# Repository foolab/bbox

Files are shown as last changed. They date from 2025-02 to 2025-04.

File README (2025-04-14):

I have been using a Node 804 for my TrueNAS server for years but I needed a new case. The 804 is great but I needed something smaller that could be shoved in an IKEA Besta cabinet.
In addition to the drive trays making me nervous as I do not want to carry 4 drives just to replace one.

I actually bought a 3D printer and started learning CAD just for that. It's my first serious design.

Requirements:
 * Shallow as I neither have a rack nor the space for one.
 * Can be printed via my Qidi Q1 Pro
 * Can fit 6-8 drives
 * Can fit my HBA and an optional GPU
 * Can fit my mATX motherboard and ATX PSU
 * Easy access for hard drives
 * Drives are positioned so that the first 8 drives will clear out the PCIE zone.
 * No glue and no threaded inserts.

Dimensions: 430mm width, 375mm depth, 176.5mm height

BOM:
3 rolls of filament. Mine is around 1.8KG without any of the front drive holders.
86 x M2 10mm counterbore screws
86 x M2 hex nuts
51 x M3 10mm countersink screws
51 x M3 hex nuts
28 6x3 circular magnets
12mm M3 motherboard standoffs + M3 nuts.
16mm PC power switch

For each fan mount:
4 x M3 screws and 4 M3 nuts (to attach each mount to 4 hdd holders).
The shorter the better. 6mm would do. Maybe even 5mm but I had only 8mm and 10mm so used 8mm

For each HDD holder:
2 x M2.5 18mm counterbore screws and 2 x 2.5M nuts for attaching the connector
1 x SFF-8482 SAS Female to SATA Male 90 degrees connector https://www.aliexpress.com/item/1005008077051668.html?spm=a2g0o.order_list.order_list_main.75.d85f18023sqB9C

For each SSD holder:
up to 3 x SFF-8482 SAS to SATA 3.0 Adapter (SATA Male to Female) `https://www.aliexpress.com/item/1005005773620960.html?spm=a2g0o.order_list.order_list_main.124.d85f18023sqB9C
I could not connect the power to all 3 adapters so used 2. It was too tight.
2 x M2.5 30mm counterbore screws and 2 x 2.5M nuts for the connectors.
3 x M2.5 18mm counterbore screws and 3 x 2.5M nuts, 1 x M2 10mm counterbore screws and 1 x M2 nut for connecting all the body pieces (Shorter screws will do).

For each side SSD holder:
2 x M2.5 18mm counterbore screws and 2 x 2.5M nuts for attaching the connector AND THE STRUCTURE TO LEFT WALL.
1 x SFF-8482 SAS to SATA 3.0 Adapter (SATA Male to Female) `https://www.aliexpress.com/item/1005005773620960.html?spm=a2g0o.order_list.order_list_main.124.d85f18023sqB9C

M2.5 counterbore screws and nuts for attaching studs, HDD and SSD holders to the case (Amount depends on the number of drives used. read below).

Printing:
I used a Qidi Q1 Pro for printing. My nozzle is 0.4 and the layer height is 0.2.
I am using Orca slicer
I had to use a glue stick otherwise prints won't release (mesh would break instead of release).
I did not want to print with support thus some parts got split insanely (The intact versions are there).
Please make sure your printer is as accurate as possible. There is not much wiggle room.
I used a mix of black and white Elegoo rapid PETG and Sunlu white PETG.
The case seems to be a bit wider at the front. Probably due to warping but the front top should bring it together nicely.

Assembly:
Instructions assume the case is oriented so that front wall is towards us.

- Bottom:
 - I planned pockets for screw heads but it was easier to use them for the nuts.
 - Bolt middle left and middle right with 3 x M2 screws and 3 x M2 nuts
 - Bolt rear left and rear right with 5 x M2 screws and 5 x M2 nuts
 - Bolt rear and middle with 12 x M2 screws and 12 x M2 nuts
 - Install the 6 magnets in the corresponding pockets in middle part

- Rear wall
 - Bolt rear PSU to the bottom using 3 x M2 screws and 3 x M2 nuts
 - Bolt rear middle to the bottom using 3 x M2 screws and 3 x M2 nuts. There are 5 holes but only 3 are usable. I might fix that in a future iteration depending on how stable the structure is.
 - Bolt rear PCI to the bottom using 4 x M2 screws and 4 x M2 nuts

- Right wall
 - Bolt rear part to the bottom using 4 x M2 screws and 4 x M2 nuts
 - Bolt front part to the bottom using 4 x M2 screws and 4 x M2 nuts

- Left wall
 - Bolt rear part to the bottom using 4 x M2 screws and 4 x M2 nuts
 - Bolt front part to the bottom using 4 x M2 screws and 4 x M2 nuts
 - Bolt front left support to the left wall using 3 x M2 screws and 3 x M2 nuts

- Front wall
 - The power button holder:
  - attached to the left wall using 3 x M2 screws and 3 x M2 nuts.
  - attached to the bottom using 1 x M2 screws and 1 x M2 nuts.
 - mesh parts and bottom front bolted together
 - Attach bottom front
  - Install 6 magnets into the pockets.
  - Bolt it using 6 x M2 screws and 6 x M2 nuts
  - Orient it so that magnets are towards the front wall and the thick part is towards the bottom.
 - 2 front supports. Each takes a magnet and 6 x M2 screws and 6 x M2 nuts.

- Bolt left wall to PCIE cutouts part using 3 x M3 screws and nuts
- Bolt PCIE cutouts part to middle part using 4 x M3 screws and nuts
- Bolt middle part to PSU part using 4 x M3 screws and nuts
- Bolt PCIE top part to middle part using 4 x M3 screws and nuts
- Corner support between rear wall and right/left walls:
 - The thin part with the hole is oriented upwards.
 - Use 6x3mm circular magnet for each
 - Use 2 x M3 screws and 2 x M3 nuts for each

- Side supports:
 - 2 side supports
 - Each takes 2 magnets
 - Each needs 8 x M3 screws and 8 x M3 nuts

- Top
 - Front parts to be connected using front top support.
  - Each top support needs 6 x M2 screws and 6 x M2 nuts.
  - Each top support needs a magnet. Make sure the orientation is correct w.r.t front support magnets.
  - 2 Magnets for front rear. Use 2 x M3 screws and 2 x M3 nuts for each.
 - Rear parts to be screwed using 4 x M3 screws and 4 x M3 nuts.
  - 4 Magnets for the rear part. Use 2 x M3 screws and 2 x M3 nuts for each.

- Motherboard standoffs
 - The case supports both ATX and mATX motherboards. You can still use mini ITX if you want.
 - ATX-only locations are labeled "A"
 - mATX-only locations are labeled "M"
 - NOTE: Not all motherboards will have holes for all standoffs. Please check before screwing your notherboard
 - Standoffs:
  - My standoffs have 6mm bottom threads and are 6mm in height.
  - I screwed 2 standoffs on top of each others to get the 12mm needed.

- PCIE covers
 - Print as much as you need.
 - They just snap into place from the outside.

- SSD side holder:
 - Attach to the left wall using 2 x M2.5 screws and 2 x 2.5M nuts.
 - The thick holder wall is towards the side wall.
 - Make sure the connector is oriented correctly otherwise the SSD will not fit.

- SSD holder:
 - It will easily come together using the M2.5 screws.
 - Join the body pieces together with the M2 and M2.5 screws and nuts.

- HDD holder:
 - Attach the connector using 2 x M2.5 screws and 2 x 2.5M nuts.

- HDD fan mount:
 - Each fan mount attaches to 4 hdd holders using 4 x M3 screws and 4 M3 nuts
 - It is supposed to be flimsy to give space for removing the drives.
 - I recommend attaching the mounts to the holders after they are installed and afterwards attach the fan.

- Drive studs and holders:
 - I used a 1mm thick rubber strip hoping it will help with HDD vibrations. No idea if it does.
 - Make sure to attach all SATA data and power cables before screwing in the holders.
 - The space is very tight.
 - The case can host up to 12 holders but I recommend no more than 8 due to space being very tight.
 - The large stud is at the front. The small stud is towards the back.
 - Make sure the large stud is oriented correctly: There are tiny pockets that go above the magnets pockets
 - Screw in studs first. For each position:
  - If it will be empty, use 3 x M2.5 14mm screws
  - If it will host an SSD holder, use 1 x M2.5 14mm screw for the top hole in the large stud.
  - If it will host an HDD holder, use 1 x M2.5 14mm screw for the small stud.
 - Holders screw on top of the studs.
 - For the holders:
  - HDD: Use 2 x M2.5 25mm screws and 2 nuts.
  - SSD: Use 1 x M2.5 18mm screw for the amall stud and 1 x M2.5 25mm screw for the large stud and 2 nuts.
 - The screws might protrude from the bottom due to inaccuracies while printing. It can be solved by using washers between the studs and the drive holders. Do NOT put the washer inside the holder itself.

- Bottom plates:
 - Attach using 3 x M2 screws and 3 x M2 nuts (Even 2 will do).
 - There are holes for 4 screws but the rightmost one is inaccessible and the rest are too difficult.
 - I ended up not attaching them :p

- Fans:
 - Use the 30mm screws.
 - I used M2.5 with a washer to prevent the screw head from going through the hole :D
 - I recommend screwing in the fans after the motherboard installation.
 - I use Noctua NF-A12x25 fans. Maybe a 15 mm would be easier to install
 - The rear has screw holes for a 92mm fan.

- Attach the power button to its holder.
- PSU: I used 4 x 6-32 8mm screws.

Github: FreeCAD files available from https://github.com/foolab/bbox

Buy me a coffee: https://ko-fi.com/msameer

BBox? It can be Bit(s) Box, Bytes Box, Bolts Box or simply Broken Box ;-)

bottom (I think I mixed up front right and left):
  rear left: 5 top layers, 5 bottom layers, 4 walls, 15% grid infill, no brim, layer height: 0.2
  rear right: 5 top layers, 5 bottom layers, 4 walls, 15% grid infill, no brim, layer height: 0.2
  middle left: 5 top layers, 5 bottom layers, 4 walls, 15% grid infill, no brim, layer height: 0.2
  middle right: 5 top layers, 5 bottom layers, 4 walls, 15% grid infill, no brim, layer height: 0.2
  front: 5 top layers, 5 bottom layers, 4 walls, 15% grid infill, no brim, layer height: 0.2
  plates: 4 top layers, 4 bottom layers, 2 walls, 15% grid infill, no brim, layer height: 0.2

front wall:
 settings: 5 top layers, 5 bottom layers, 4 walls, 15% gyroid infill, no brim, layer height: 0.2
 mesh parts:
   Add part: cube
   cube part: 0 top layers and 0 bottom layers
    left:
      cube part position: x: -1.23, y: 5.5, z: 0
      cube part size: x: 120, y: 158.5, z: 3
    middle:
      cube part position: x: 0.4, y: 5.5, z: 0
      cube part size: x: 120, y: 158.5, z: 3
    right:
      cube part position: x: 0.82, y: 5.5, z: 0
      cube part size: x: 120, y: 158.5, z: 3

left wall:
  front: 5 top layers, 5 bottom layers, 4 walls, 15% grid infill, no brim, layer height: 0.2
  rear:
    settings: 5 top layers, 5 bottom layers, 4 walls, 15% gyroid infill, no brim, layer height: 0.2
    Add part: disc
    disc part: 0 top walls and 0 bottom walls
    disc part position: x: -8.54, y: 9.75, z: 0
    disc part size: x: 118, y: 118, z: 4

right wall:
  front: 5 top layers, 5 bottom layers, 4 walls, 15% grid infill, no brim, layer height: 0.2
  rear:
    settings: 5 top layers, 5 bottom layers, 4 walls, 15% gyroid infill, no brim, layer height: 0.2
    Add part: cube
    cube part: 0 top walls and 0 bottom walls
    cube part position: x: 8.54, y: -3.25, z: 0
    cube part size: x: 130, y: 146, z: 4

drive cage studs: 4 wall loops, 5 top layers, 5 bottom layers, 40% grid infill, no brim

rear:
  middle: 5 top layers, 5 bottom layers, 4 walls, 15% grid infill, no brim, layer height: 0.2
  psu: 5 top layers, 5 bottom layers, 4 walls, 15% grid infill, no brim, layer height: 0.2
  pcie combined: 5 top layers, 5 bottom layers, 4 walls, 15% grid infill, no brim, layer height: 0.2

top:
	rear left: 4 top layers, 4 bottom layers, 2 walls, 15% grid infill, no brim, layer height: 0.2
	rear right: 4 top layers, 4 bottom layers, 2 walls, 15% grid infill, no brim, layer height: 0.2
	front left: 4 top layers, 4 bottom layers, 2 walls, 15% grid infill, no brim, layer height: 0.2
	front middle: 4 top layers, 4 bottom layers, 2 walls, 15% grid infill, no brim, layer height: 0.2
	front right: 4 top layers, 4 bottom layers, 2 walls, 15% grid infill, no brim, layer height: 0.2

pcie slot cover: 2 top layers, 2 bottom layers, 2 walls, 10% grid infill, no brim, layer height: 0.2

supports and magnets: 5 top layers, 5 bottom layers, 4 walls, 15% grid infill, no brim, layer height: 0.2
ssd side holder: 5 top layers, 5 bottom layers, 4 walls, 15% grid infill, no brim, layer height: 0.2
ssd holder: 5 top layers, 5 bottom layers, 4 walls, 15% grid infill, no brim, layer height: 0.2
hdd fan mount: 4 top layers, 2 bottom layers, 4 walls, 40% grid infill, no brim, layer height: 0.2
hdd holder: 5 top layers, 5 bottom layers, 4 walls, 15% grid infill, no brim, layer height: 0.2

TODO:
rear middle has 5 screw holes but bottom has 4 pockets only.
rear middle 1 screw has no place for the bolt. too tight.
bottom plates, 1 screw is inaccessible and screws are too difficult
decrease motherboard standoff heights
bottom is too difficult to assemble
Increase the hdd holder base height by 1 mm
design a double side ssd holder

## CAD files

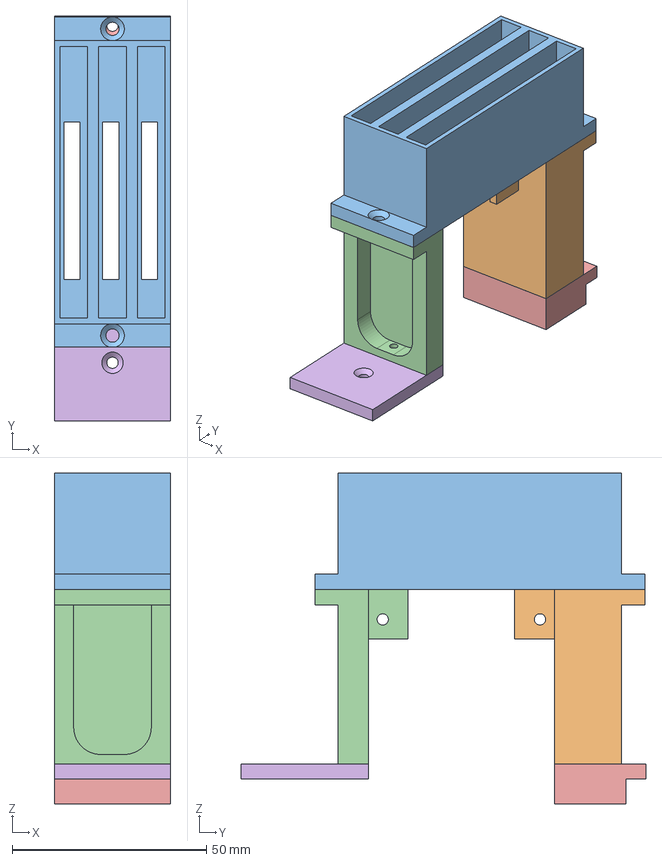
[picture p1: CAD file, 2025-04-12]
ssd holder.FCStd
30.0 x 104.3 x 85.2 mm
Slice.0
Slice.1
Slice.2
Slice.3
Slice.4

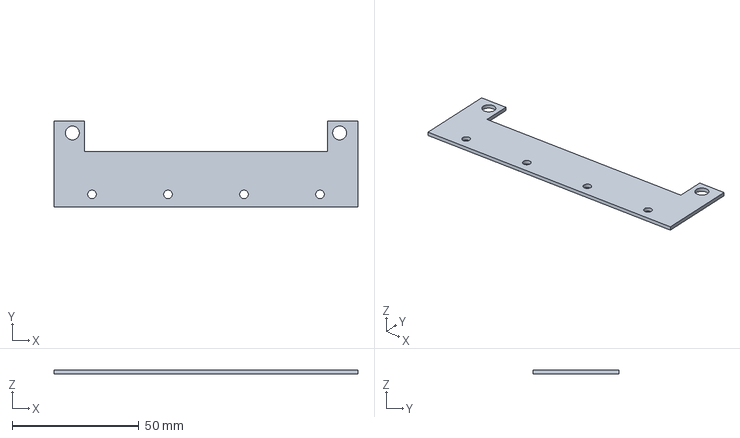
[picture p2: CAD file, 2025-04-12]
hdd fan mount.FCStd
120.0 x 34.0 x 1.50 mm

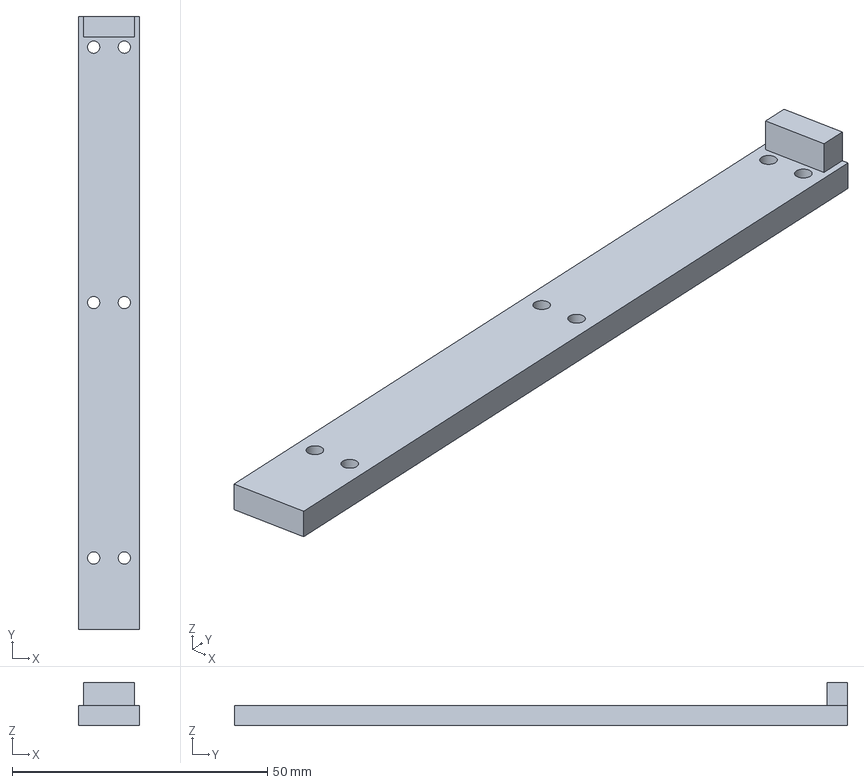
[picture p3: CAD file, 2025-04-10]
front support.FCStd
12.0 x 120.0 x 8.50 mm

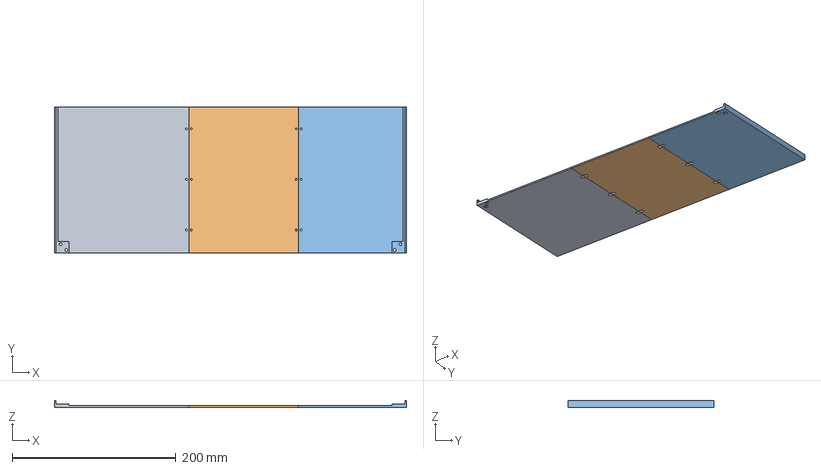
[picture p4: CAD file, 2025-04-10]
top.FCStd
430.0 x 178.0 x 8.00 mm
Slice001.0
Slice001.1
Slice001.2

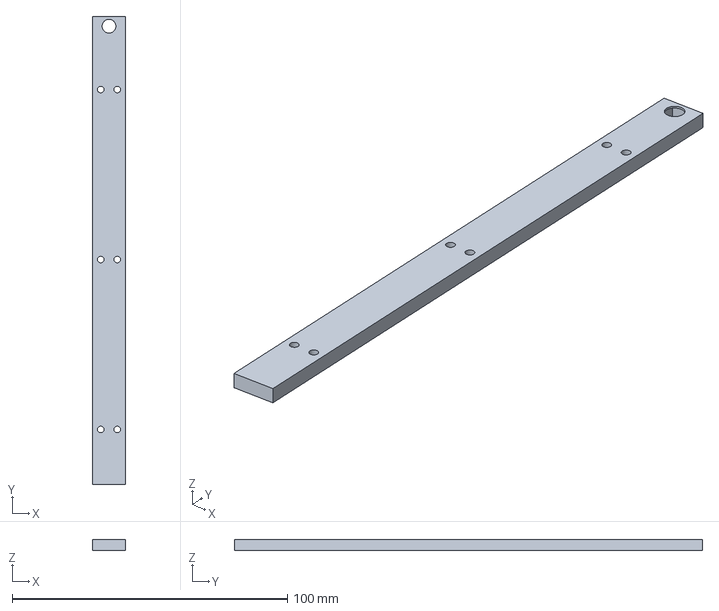
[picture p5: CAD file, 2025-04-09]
top front support.FCStd
12.0 x 170.0 x 4.00 mm

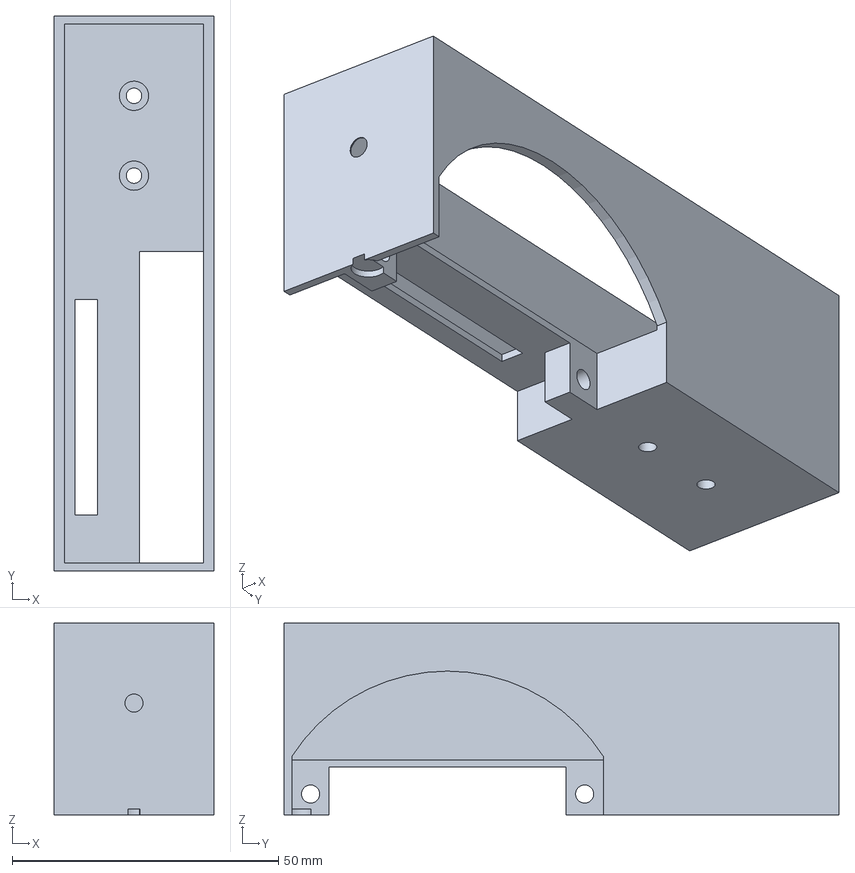
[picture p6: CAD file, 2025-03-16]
hdd holder.FCStd
30.0 x 104.3 x 36.0 mm

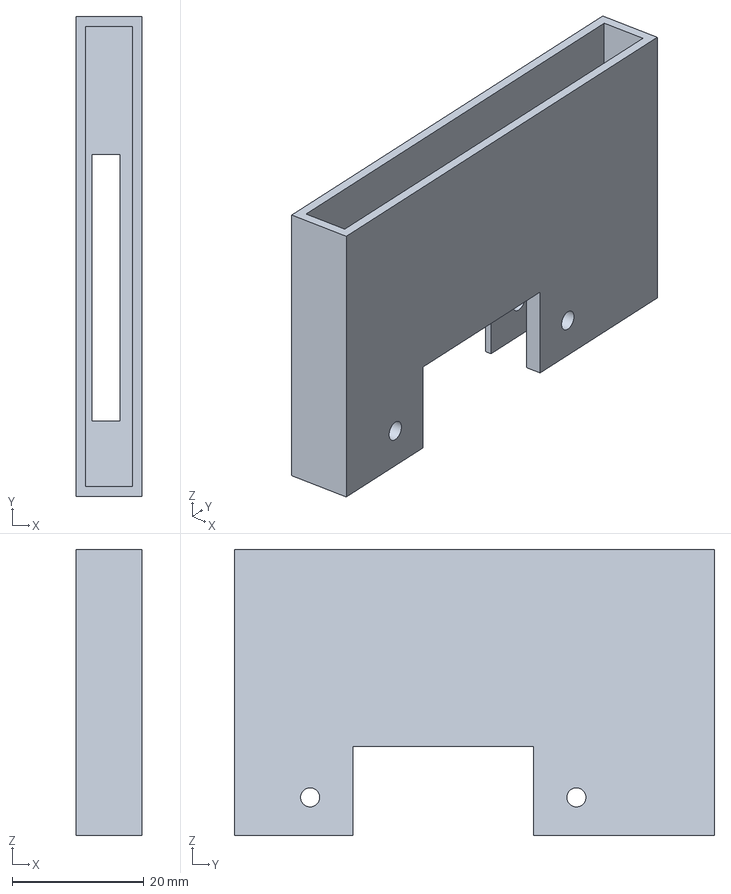
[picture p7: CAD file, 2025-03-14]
ssd side holder.FCStd
10.0 x 73.0 x 43.5 mm

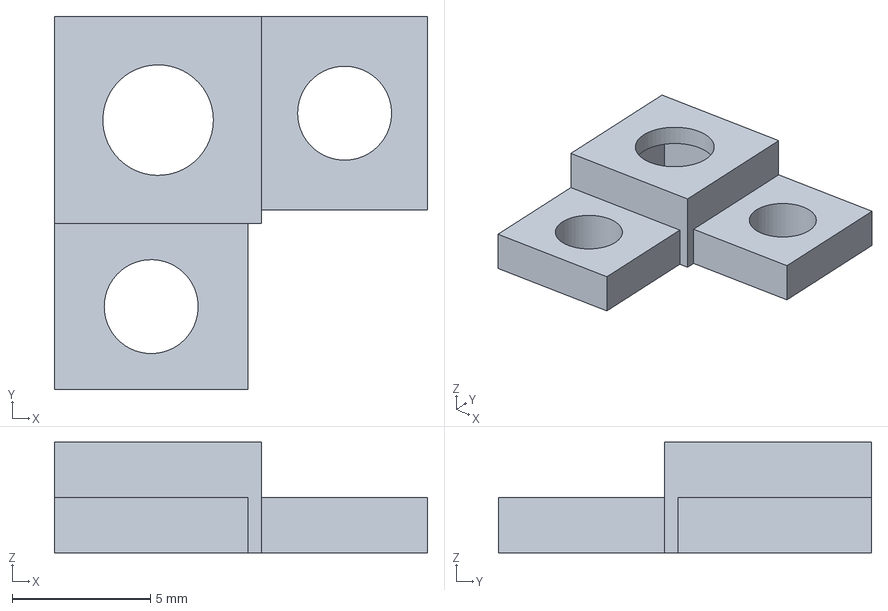
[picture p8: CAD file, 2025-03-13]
top corner magnet.FCStd
13.5 x 13.5 x 4.00 mm

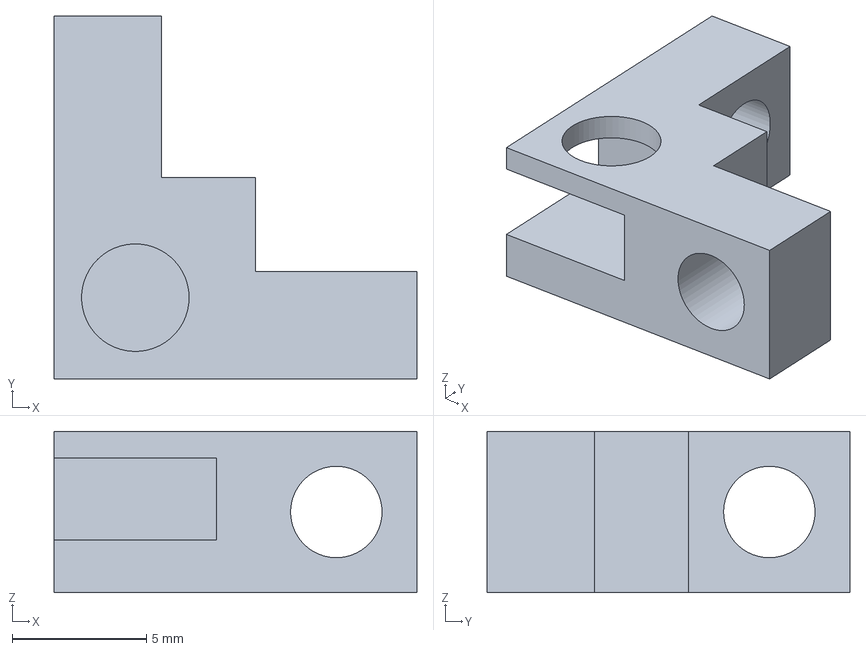
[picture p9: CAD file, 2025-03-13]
corner support.FCStd
13.5 x 13.5 x 6.00 mm

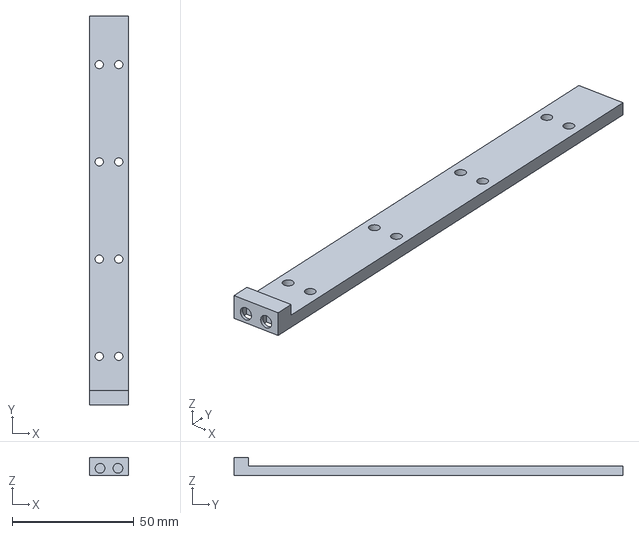
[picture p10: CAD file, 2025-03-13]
side support.FCStd
16.0 x 160.0 x 7.50 mm

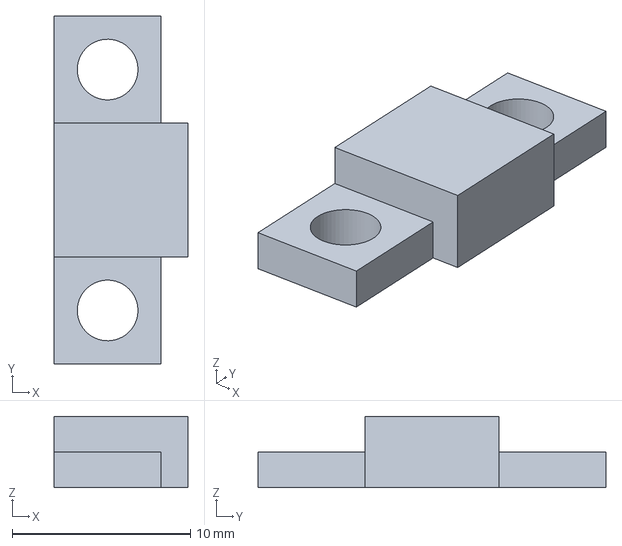
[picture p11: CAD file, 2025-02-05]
top side magnet.FCStd
7.50 x 19.5 x 4.00 mm

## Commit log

2025-01-28 HDD and SSD enclosures
    [hdd enclosure.FCStd, ssd enclosure.FCStd]
2025-01-28 HDD fan hinge and mount
    [hdd fan hinge 1.FCStd, hdd fan hinge 2.FCStd]
2025-01-29 rename ssd and hdd enclosure to holder
    [hdd holder.FCStd, ssd holder.FCStd]
2025-02-01 Initial case
2025-02-01 side fan is an intake. We will use mesh for it
2025-02-02 case: Add pockets for drive studs, motherboard standoffs and front magnets
2025-02-02 case: Add left wall support needed for splitting the piece
2025-02-02 case: Get rid of the gap behind the PSU
2025-02-02 Fixed rear fan mount holes and slightly increased the ventilation opening
2025-02-03 Add side support. used to join side wall parts
    [side support.FCStd]
2025-02-03 side support: decrease width to 16mm
    [side support.FCStd]
2025-02-03 side support: Make the distance between holes 6mm to account for screw heads
    [side support.FCStd]
2025-02-03 side support: Make the distance between holes 8mm instead of 6mm
    [side support.FCStd]
2025-02-03 case: Add left wall holes for side support instead of the built in support previously planned
2025-02-03 case: Add right wall holes for side support and adjust left holes position to be closer to the front
2025-02-03 Add corner support. It is mainly used to support the top part
    [corner support.FCStd]
2025-02-03 Add holes for corner support
2025-02-04 corner support: Reworked to be 6mm thick
    [corner support.FCStd]
2025-02-04 side support: make depth 7.5mm instead of 7.55mm
    [side support.FCStd]
2025-02-05 side support: Make some space for case top magned and better to have 0.5mm gap between them
    [side support.FCStd]
2025-02-05 case: Make some space for case top magned and better to have 0.5mm gap between them
2025-02-05 design top support, Adjust case top support height, adjust side suport height and add back support for the case top panel.
    [side support.FCStd, top corner magnet.FCStd, top side magnet.FCStd]
2025-02-09 case: cut the extra back bottom part. This should be in the bottom sketch but it's too late now to fix
2025-02-09 case: split the bottom front drives cage pocket
2025-02-12 Add side and bottom screw holes
2025-02-12 Add paddings for rear screws
2025-02-12 case: remove rear top support. Not really needed and cannot really be printed as we have a few pads on the other side
2025-02-14 case: Add side ssd screw holes
2025-02-14 Add SSD side holder
    [ssd side holder.FCStd]
2025-02-14 Add a blank top
    [top.FCStd]
2025-02-15 left support screws were completely off. Fix it and fix the bottom part of the case too
2025-02-16 case: Assign each wall a variable for height and adjust them so front and rear walls have full height
2025-02-16 case: remove bottom front wall screws as we will not screw it to the base. It will be removable
2025-02-16 case: Add the power button holder
2025-02-16 Updated due to object location changes
    [hdd fan hinge 1.FCStd, hdd fan hinge 2.FCStd, hdd holder.FCStd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]
2025-02-16 case: increase keepout area between rear support and motherboard IO cutout to 5mm. 2.5 was very tight when we attempt to cut
2025-02-16 case: Fixed misplaced rear support screw holes
2025-02-16 case: Add an extra 0.1mm padding above the front magnets because the front one is still hidden after slicing
2025-02-16 adjust sidewall screw holes position as they were being cut while slicing
2025-02-16 case: PSU side bottom screw hole was completely off. Fix it
2025-02-16 case: Add an extra rear bottom screw. Not the most elegant way but I don't want to redo most of the model
2025-02-17 case: Fix the screw hole connecting PCIE flange and cutouts part. It was incomplete and also adjust its position
2025-02-17 case: Front wall will be bolted. Add pockets for the nuts
2025-03-03 case: split
2025-03-03 top corner magnet: Move screw hole a bit from the edge. It was affecting padding for the top panel
    [top corner magnet.FCStd]
2025-03-03 Reworked power button.
    - Push it backwards a bit to allow some space between it and the front wall.
    Issue revealed after printing front wall
    - Decrease the thickness of the power button holding ring in order not to potentially interfere with drives
    - Added a fillet to try to strengthen that part a bit.
    - I had to resplit the case although just to extract this part
2025-03-03 Side fan: set screws to counterbore
2025-03-03 fix screws for rear fan to be counterbore and increase support. Also resplit right wall front because we left 0.05mm instead of 0.1mm between rear and front parts
2025-03-03 I had to recut the middle rear manually.
    Changing the offset for the power button seems to have broken FreeCAD. I need to redo the splitting
    to fix the file :/
2025-03-03 Trying to fix broken sketches and set proper SSD screws type to counterbore
2025-03-03 case: Fixed broken left wall sketch
2025-03-03 case: Fixed right wall sketch
2025-03-03 case: I think I fixed the model. Had to create most of the splitting sketches
2025-03-03 case: rear wall middle part was not cut correctly. Fix that
2025-03-03 case: remove redundant slices
2025-03-04 case: Add proper screw holes for PSU
2025-03-04 rework pcie fasteners
    - Enlarge the holes to accommodate UNC #6 screws
    - Add enough clearance to allow screwing from the bottom
    - Beautify the area a bit with fillets.
    - Ideally we should get rid of the old cruft but I do not want to readjust the design after removing "pcie fasteners" pocket.
2025-03-06 hdd holder: Fix screws
    - Our screws are counterbore.
    - Add a pocket to accommodate the screw head for the small stud
    [hdd holder.FCStd]
2025-03-06 ssd holder: Host 3 SSDs instead of 2 and fix screw heads to be counterbore
    [ssd holder.FCStd]
2025-03-13 Add holes for magnets
    [corner support.FCStd, side support.FCStd, top corner magnet.FCStd]
2025-03-13 case: switch counterbore heads to countersink because it will not print correctly
2025-03-14 ssd side holder: Make it splittable vertically.
    We achieve that by adding a front protrusion so the connector screw goes through it screwing
    both halves together. Now we can easily print the part ;-)
    [ssd side holder.FCStd]
2025-03-15 ssd holder: Add side screw holes so we can screw it back after splitting.
    And also add a padding for bottom screws
    [ssd holder.FCStd]
2025-03-15 ssd holder: cosmetic changes
    set proper names for body parts
    Add a bit of clearance to the small stud flange
    [ssd holder.FCStd]
2025-03-15 ssd holder: reworked so it can be split and printed
    Too many parts and screws for my liking but it is what it is :/
    [ssd holder.FCStd]
2025-03-16 ssd holder: convert base screw heads to countersink
    This to make it printable.
    The pocket for the base screw is not printing correctly. I have to flip the part to print it.
    counterbore heads however will not print correctly when flipped.
    [ssd holder.FCStd]
2025-03-16 hdd fan hinge 1: Magnet pocket should be moved to the back side
    [hdd fan hinge 1.FCStd]
2025-03-16 hdd holder: split
    [hdd holder.FCStd]
2025-03-17 case: Some bottom screws were M1 by mistake. Switch them to M2.
2025-03-19 case, top: Add a lip to top front so it can stay in place
    [top.FCStd]
2025-03-20 top: Add some wiggle room so the cover will fit.
    [top.FCStd]
2025-03-22 top: reworked to use screws for the rear part
    [top.FCStd]
2025-03-22 case: rework bottom front to completely enclose the magnets. Need to redo the modifications into the main design.
2025-03-23 hdd fan hinge 2: Rework magnets pockets.
    [hdd fan hinge 2.FCStd]
2025-03-24 hdd fan hinge 2: Remove rear screw holes.
    [hdd fan hinge 2.FCStd]
2025-04-04 Reworked to give space to HDD cables.
    - Give more space to get cables out of drives part
    - Add a pocket beneath the drives.
    - The rightmost 8 drives should now fit before the first PCIE slot.
    - Incorporate the front part changes regarding magnets.
    - All slicing needs to be redone :'-(
2025-04-09 More work.
    Reworked top front.
    Reworked front wall.
    Many more.
    [front support.FCStd, top front support.FCStd, top.FCStd]
2025-04-10 top: front magnet screw holes are countersink
    [top.FCStd]
2025-04-10 front support: Fix screw positions so it clears top support
    [front support.FCStd]
2025-04-10 case: slice rear wall
2025-04-12 case: Hack around incorrect motherboard height
    The IO cutout is too high and the motherboard IO area will not fit properly.
    We need longer standoffs which is impractical.
    The issue is the stiffening ribs should not have been added to the height.
    Removing it now will cause an avalanche and the whole slicing will have to be redone.
    We also need longer standoffs than the 6.5 I am planning to use to allow the end of PCIE brackets
    to sit. It should be 9.5 or we curve a slot into the bottom for the ends which is too much work.
    I am however using 12 by stacking 2 x 6mm since it is what I have.
    The whole plan was to make the motherboard low enough to allow the fan hinge but it is what it is now.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
2025-04-12 replace fan hinge with a simple fan mount.
    The hinge takes a lot of space. Motherboard cannot be installed due to space.
    [hdd fan hinge 1.FCStd, hdd fan hinge 2.FCStd, hdd fan mount.FCStd]
2025-04-12 ssd holder: tweaks.
    Increase feet height because the power plugs were hitting the studs.
    Slightly increase the gap between the feet.
    [ssd holder.FCStd]
